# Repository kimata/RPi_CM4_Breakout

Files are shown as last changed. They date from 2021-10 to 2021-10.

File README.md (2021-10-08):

# RPi_CM4_Breakout

## 概要

Raspberry Pi Compute Module 4 から，通常の Raspberry Pi にあるピンヘッダを取り出す基板です．
サイズと穴位置は秋月のユニバーサル基板Ｃタイプに合わせてあります．

おまけで，I2C 用のピンヘッダ用のランドも設けています．

## 外観

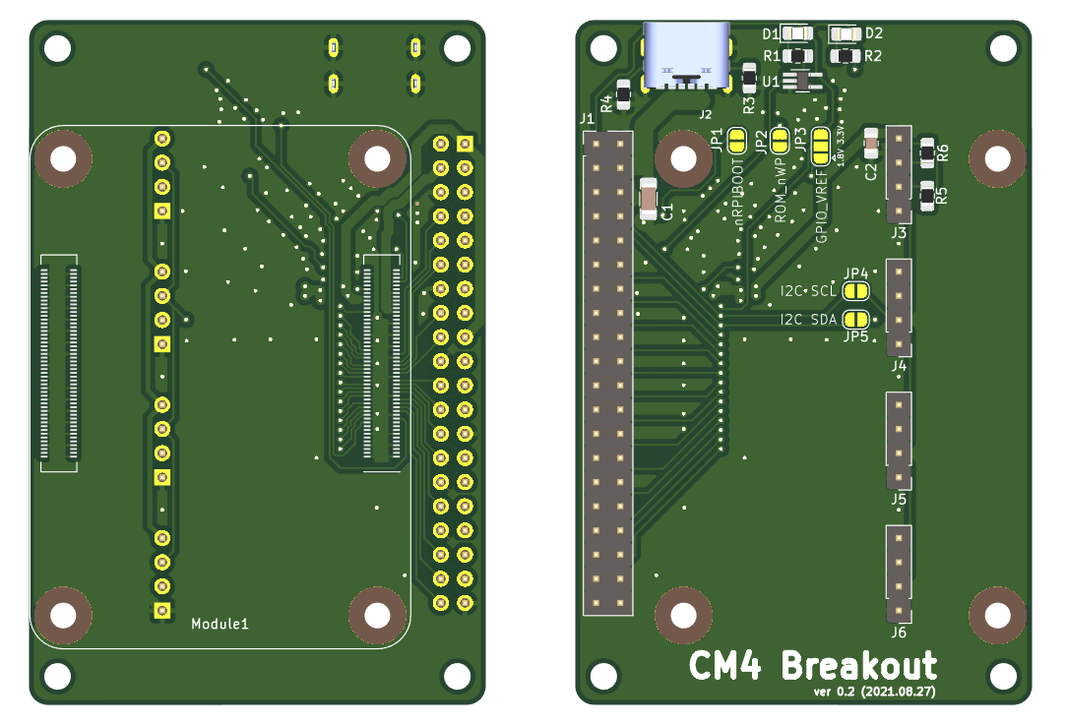
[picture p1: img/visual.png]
外観


## 回路図

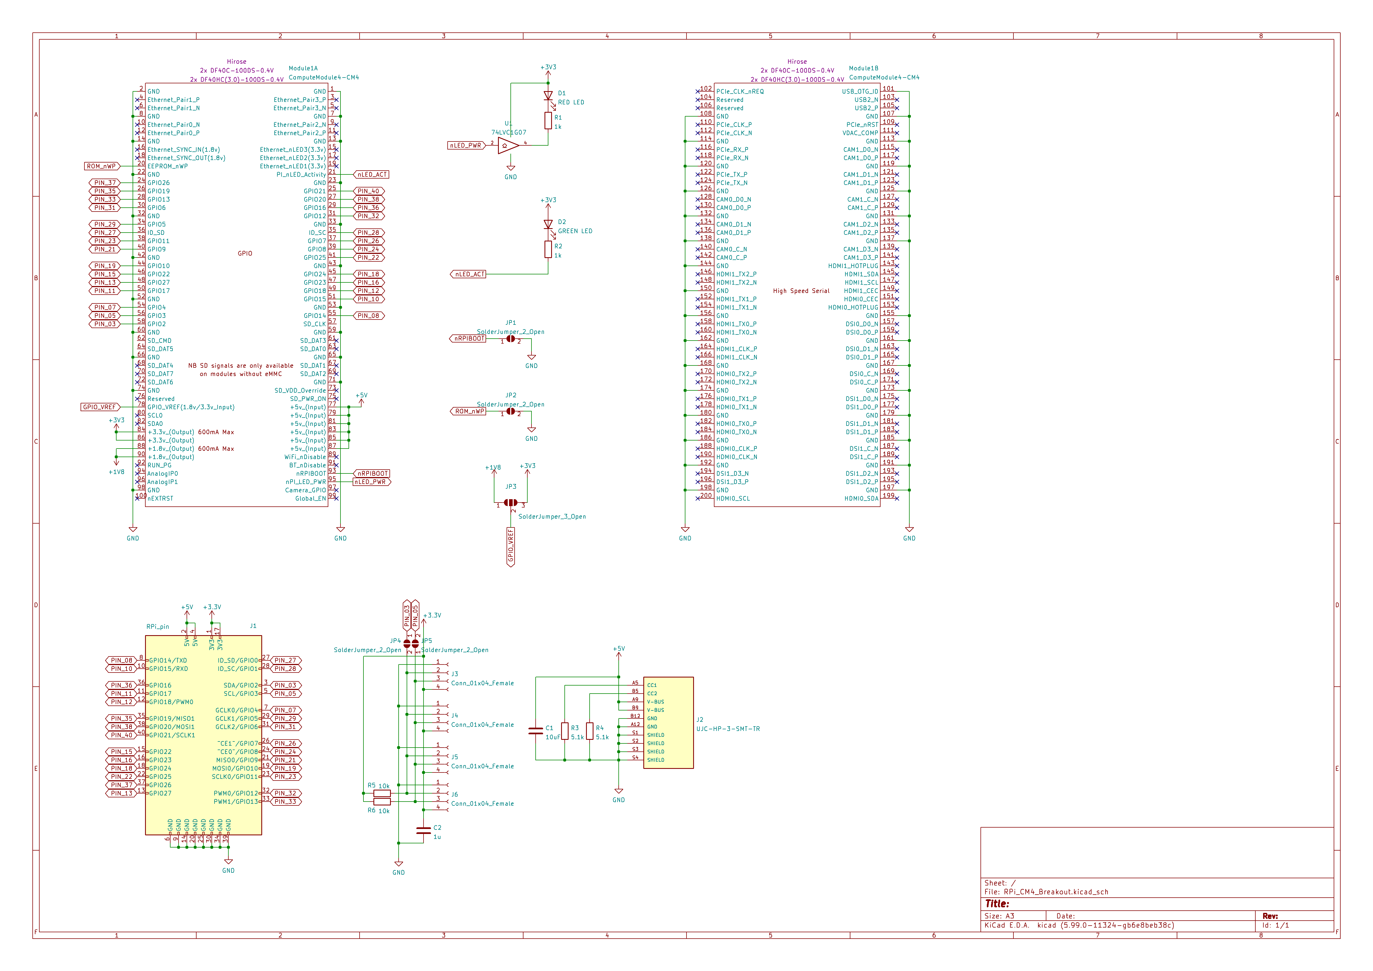
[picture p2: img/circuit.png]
回路図


## 基板の発注について

Raspberry Pi Compute Module 4 との接続に使う 100 ピンコネクタは手はんだが難しいので，この部分だけ基板メーカで実装してもらうのがおすすめです．

Elecrow にオーダーする際のシートを misc/Elecrow-PCBA-Quotation.xlsx においておきましたので参考にしてください．このファイルとガーバーデータを送れば製造できます．

料金は，私が製造したときは，送料込みで $168 でした．

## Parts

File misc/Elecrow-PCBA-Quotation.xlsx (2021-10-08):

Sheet: PCB Specification
Your PCB Specification
PCB Quantity | 10pcs
Layer | 2layer
PCB Thickness | 1.6mm
Dimensions | 48mm*72mm
Castellated Hole | No
PCB Color | Green
Surface Finish | HASL Lead Free
Copper Weight | 1oz
Text Color | White
Different Design | 1
Please find more PCB information on our on-line PCB ordering Page
https://www.elecrow.com/pcb-manufacturing.html

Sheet: BOM
Project Name
# | Reference | QTY | Value | Package | Manufacturer Part number | Description | SMD | THT | Original | Elecrow PN | Note
1 | J7, J8 | 1 |  |  | DF40HC(3.0)-100DS-0.4V(51 |  | 2 |  | Y
 |  |  |  |  |  | total： | 2 | 0
 | Declare：
 | 1、If the component should be original like Digi-key or Mouser，the component must have complete Manufacture part number

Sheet: Parts Mapping
Remarks:
- Apply solder paste only to J7 and J8 on the bottom surface and mount them.
- Flux should be cleaned after reflow.

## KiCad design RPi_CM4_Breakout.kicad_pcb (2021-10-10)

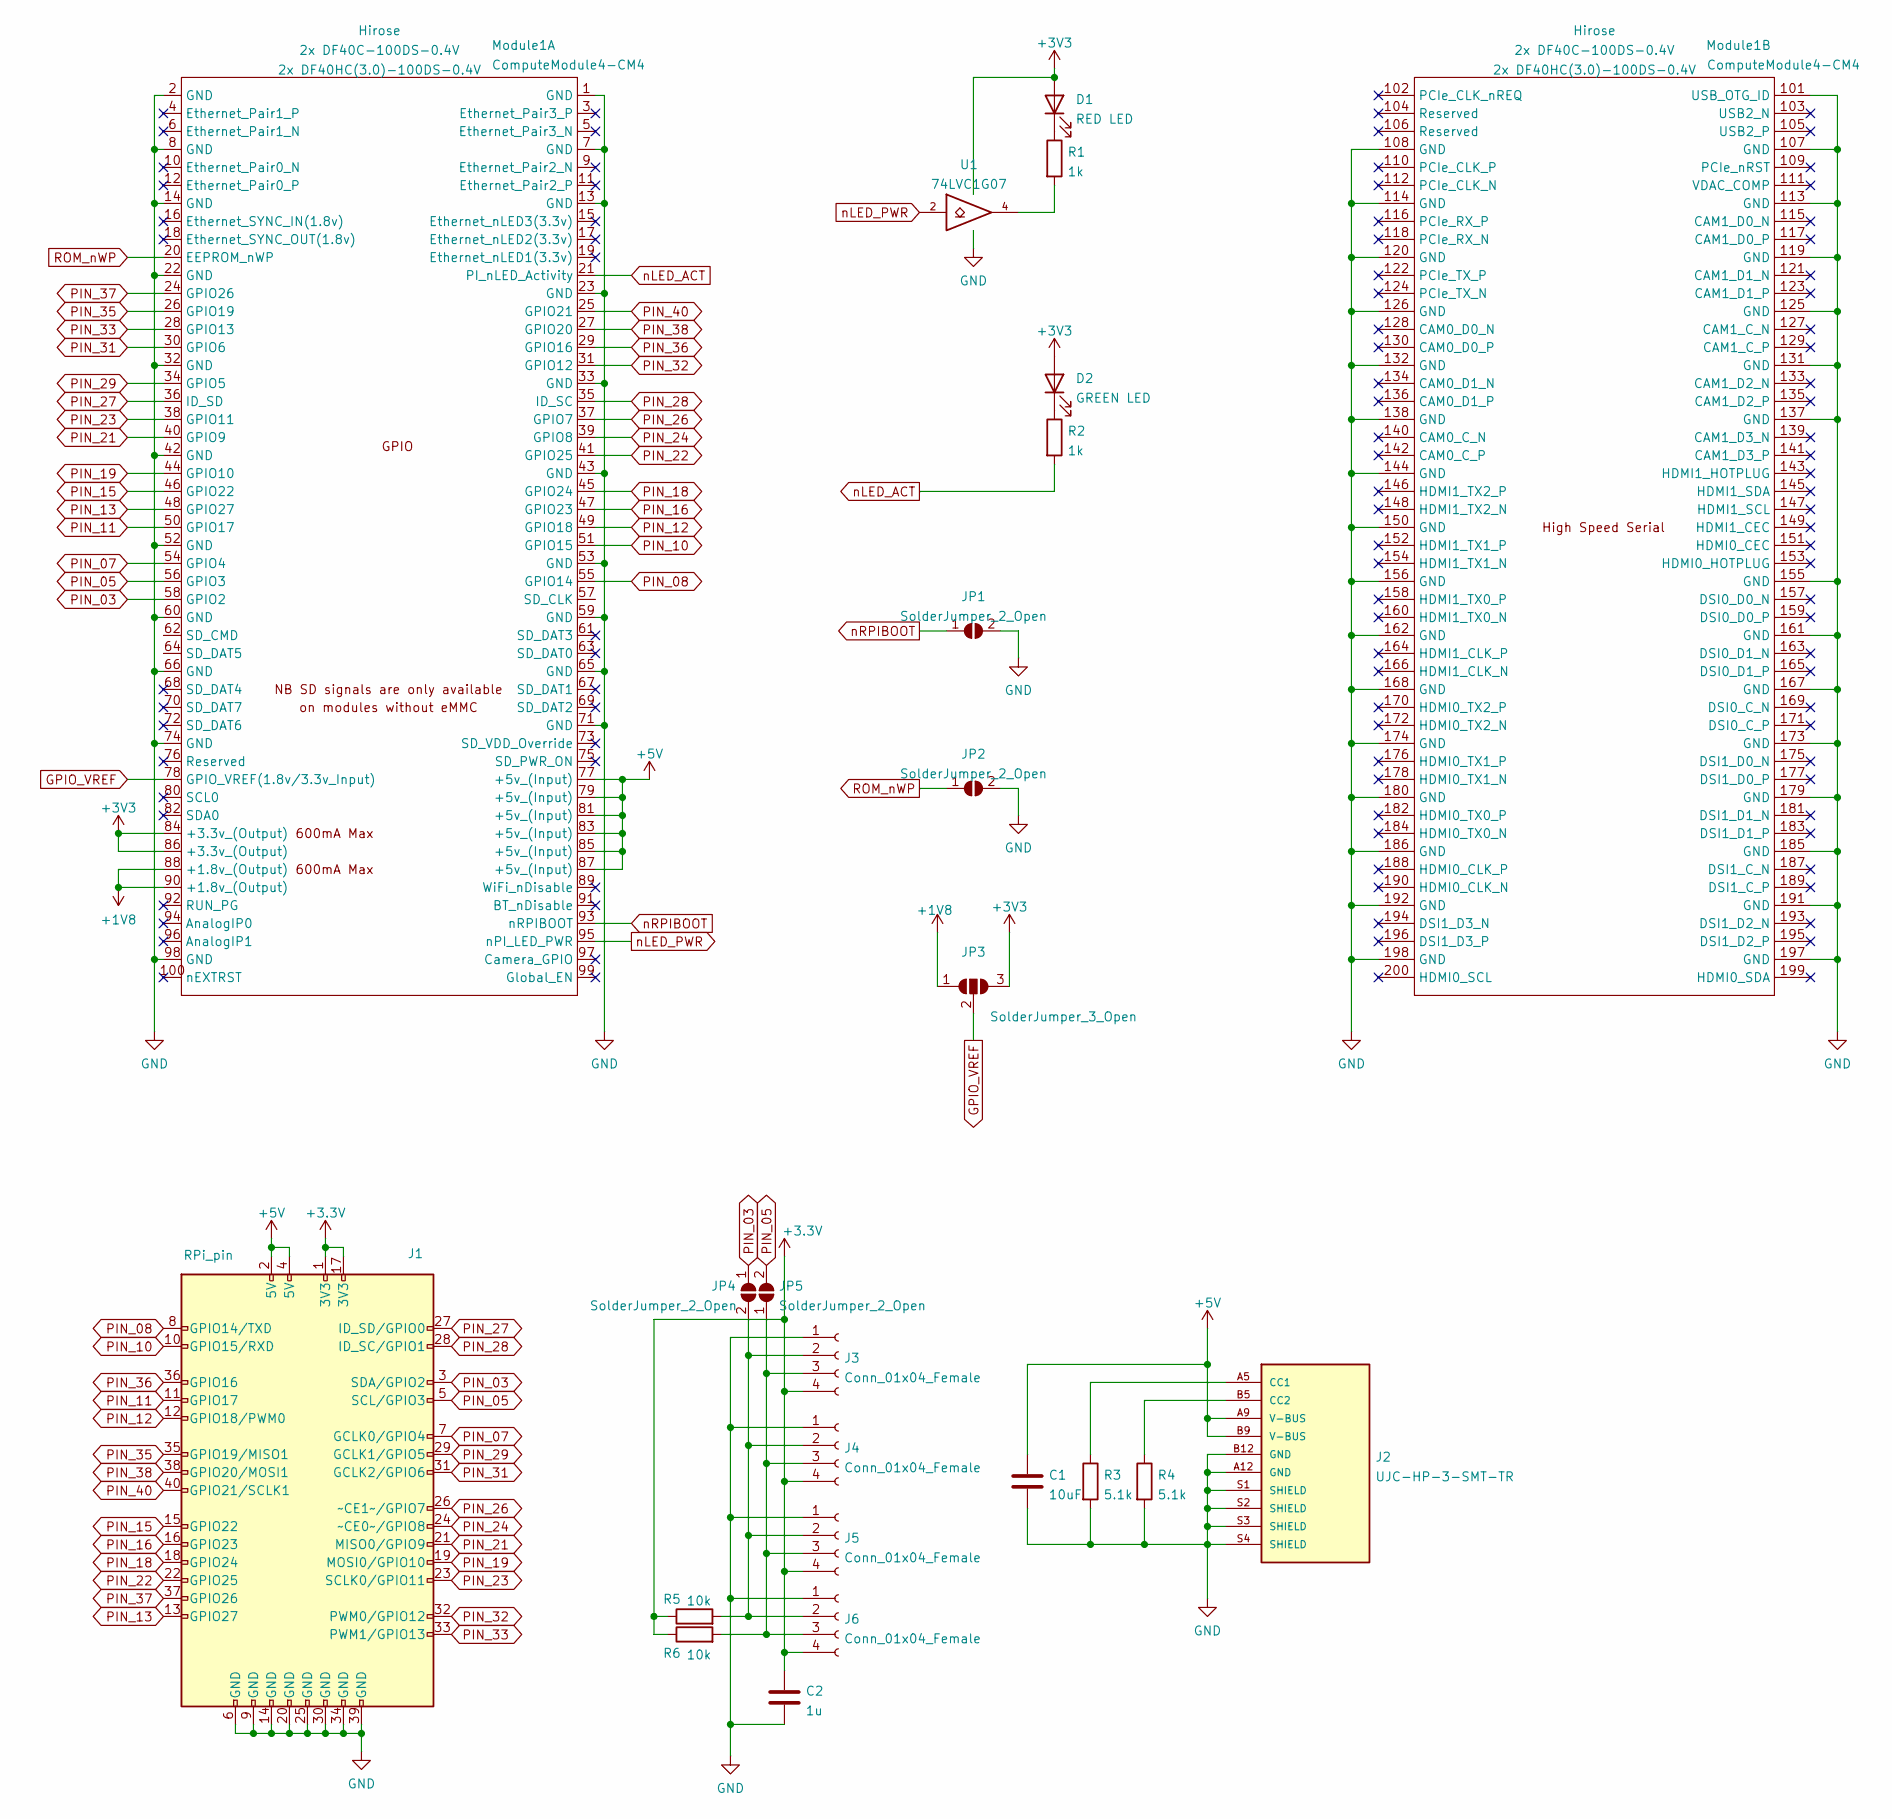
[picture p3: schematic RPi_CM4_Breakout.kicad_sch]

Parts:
C1: 10uF; C_1206_3216Metric_Pad1.33x1.80mm_HandSolder
C2: 1u; C_0805_2012Metric_Pad1.18x1.45mm_HandSolder
D1: RED LED; LED_0805_2012Metric_Pad1.15x1.40mm_HandSolder
D2: GREEN LED; LED_0805_2012Metric_Pad1.15x1.40mm_HandSolder
J1: RPi_pin; PinHeader_2x20_P2.54mm_Vertical
J2: UJC-HP-3-SMT-TR; CUI_UJC-HP-3-SMT-TR
J3, J4, J5, J6: Conn_01x04_Female; PinHeader_1x04_P2.54mm_Vertical
JP1, JP2, JP4, JP5: SolderJumper_2_Open; SolderJumper-2_P1.3mm_Open_RoundedPad1.0x1.5mm
JP3: SolderJumper_3_Open; SolderJumper-3_P1.3mm_Open_RoundedPad1.0x1.5mm
Module1: ComputeModule4-CM4; Raspberry-Pi-4-Compute-Module; MPN 2x DF40C-100DS-0.4V; Digi-Key_PN 2x H11615CT-ND
R1, R2: 1k; R_0805_2012Metric_Pad1.20x1.40mm_HandSolder
R3, R4: 5.1k; R_0805_2012Metric_Pad1.20x1.40mm_HandSolder
R5, R6: 10k; R_0805_2012Metric_Pad1.20x1.40mm_HandSolder
U1: 74LVC1G07; SOT-753

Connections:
+1V8: JP3.1 (A), Module1.88 (+1.8v_(Output)), Module1.90 (+1.8v_(Output))
+5V: C1.1, J1.2 (5V), J1.4 (5V), J2.A9 (V-BUS), J2.B9 (V-BUS), Module1.77 (+5v_(Input)), Module1.79 (+5v_(Input)), Module1.81 (+5v_(Input)), Module1.83 (+5v_(Input)), Module1.85 (+5v_(Input)), Module1.87 (+5v_(Input))
GND: C1.2, C2.2, J1.6 (GND), J1.9 (GND), J1.14 (GND), J1.20 (GND), J1.25 (GND), J1.30 (GND), J1.34 (GND), J1.39 (GND), J2.A12 (GND), J2.B12 (GND), J2.S1 (SHIELD), J2.S2 (SHIELD), J2.S3 (SHIELD), J2.S4 (SHIELD), J3.1, J4.1, J5.1, J6.1, JP1.2 (B), JP2.2 (B), Module1.1 (GND), Module1.2 (GND), Module1.7 (GND), Module1.8 (GND), Module1.13 (GND), Module1.14 (GND), Module1.22 (GND), Module1.23 (GND), Module1.32 (GND), Module1.33 (GND), Module1.42 (GND), Module1.43 (GND), Module1.52 (GND), Module1.53 (GND), Module1.59 (GND), Module1.60 (GND), Module1.65 (GND), Module1.66 (GND), Module1.71 (GND), Module1.74 (GND), Module1.98 (GND), Module1.101 (USB_OTG_ID), Module1.107 (GND), Module1.108 (GND), Module1.113 (GND), Module1.114 (GND), Module1.119 (GND), Module1.120 (GND), Module1.125 (GND), Module1.126 (GND), Module1.131 (GND), Module1.132 (GND), Module1.137 (GND), Module1.138 (GND), Module1.144 (GND), Module1.150 (GND), Module1.155 (GND), Module1.156 (GND), Module1.161 (GND), Module1.162 (GND), Module1.167 (GND), Module1.168 (GND), Module1.173 (GND), Module1.174 (GND), Module1.179 (GND), Module1.180 (GND), Module1.185 (GND), Module1.186 (GND), Module1.191 (GND), Module1.192 (GND), Module1.197 (GND), Module1.198 (GND), R3.2, R4.2, U1.3 (GND)
GPIO_VREF: JP3.2 (C), Module1.78 (GPIO_VREF(1.8v/3.3v_Input))
unnamed: D1.1 (K), R1.1
unnamed: D2.1 (K), R2.1
unnamed: J2.A5 (CC1), R3.1
unnamed: J2.B5 (CC2), R4.1
unnamed: J3.2, J4.2, J5.2, J6.2, JP4.2 (B), R5.2
unnamed: J3.3, J4.3, J5.3, J6.3, JP5.1 (A), R6.2
unnamed: R1.2, U1.4
PIN_03: J1.3 (SDA/GPIO2), JP4.1 (A), Module1.58 (GPIO2)
PIN_05: J1.5 (SCL/GPIO3), JP5.2 (B), Module1.56 (GPIO3)
PIN_07: J1.7 (GCLK0/GPIO4), Module1.54 (GPIO4)
PIN_08: J1.8 (GPIO14/TXD), Module1.55 (GPIO14)
PIN_10: J1.10 (GPIO15/RXD), Module1.51 (GPIO15)
PIN_11: J1.11 (GPIO17), Module1.50 (GPIO17)
PIN_12: J1.12 (GPIO18/PWM0), Module1.49 (GPIO18)
PIN_13: J1.13 (GPIO27), Module1.48 (GPIO27)
PIN_15: J1.15 (GPIO22), Module1.46 (GPIO22)
PIN_16: J1.16 (GPIO23), Module1.47 (GPIO23)
PIN_18: J1.18 (GPIO24), Module1.45 (GPIO24)
PIN_19: J1.19 (MOSI0/GPIO10), Module1.44 (GPIO10)
PIN_21: J1.21 (MISO0/GPIO9), Module1.40 (GPIO9)
PIN_22: J1.22 (GPIO25), Module1.41 (GPIO25)
PIN_23: J1.23 (SCLK0/GPIO11), Module1.38 (GPIO11)
PIN_24: J1.24 (~CE0~/GPIO8), Module1.39 (GPIO8)
PIN_26: J1.26 (~CE1~/GPIO7), Module1.37 (GPIO7)
PIN_27: J1.27 (ID_SD/GPIO0), Module1.36 (ID_SD)
PIN_28: J1.28 (ID_SC/GPIO1), Module1.35 (ID_SC)
PIN_29: J1.29 (GCLK1/GPIO5), Module1.34 (GPIO5)
PIN_31: J1.31 (GCLK2/GPIO6), Module1.30 (GPIO6)
PIN_32: J1.32 (PWM0/GPIO12), Module1.31 (GPIO12)
PIN_33: J1.33 (PWM1/GPIO13), Module1.28 (GPIO13)
PIN_35: J1.35 (GPIO19/MISO1), Module1.26 (GPIO19)
PIN_36: J1.36 (GPIO16), Module1.29 (GPIO16)
PIN_37: J1.37 (GPIO26), Module1.24 (GPIO26)
PIN_38: J1.38 (GPIO20/MOSI1), Module1.27 (GPIO20)
PIN_40: J1.40 (GPIO21/SCLK1), Module1.25 (GPIO21)
ROM_nWP: JP2.1 (A), Module1.20 (EEPROM_nWP)
nLED_ACT: Module1.21 (PI_nLED_Activity), R2.2
nLED_PWR: Module1.95 (nPI_LED_PWR), U1.2
nRPIBOOT: JP1.1 (A), Module1.93 (nRPIBOOT)

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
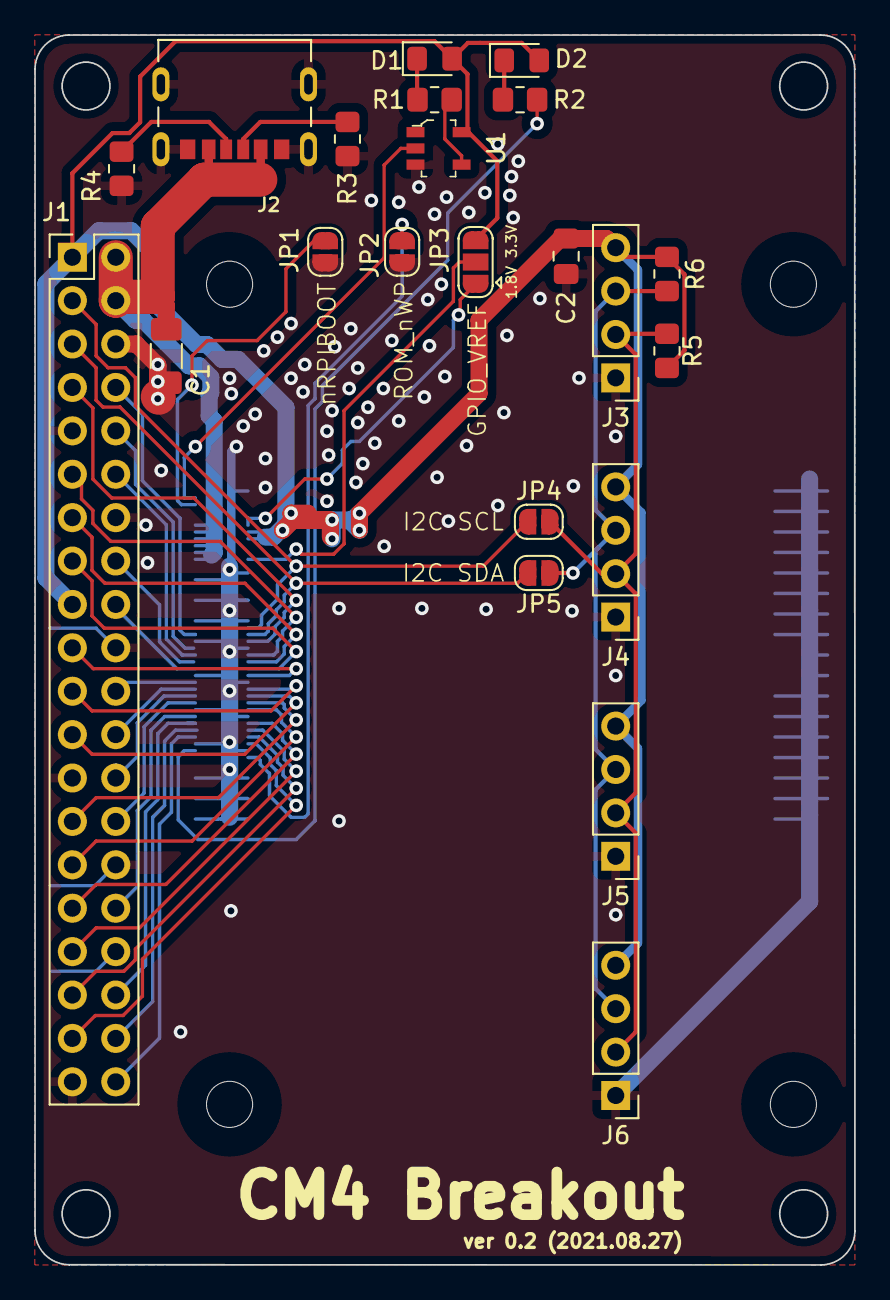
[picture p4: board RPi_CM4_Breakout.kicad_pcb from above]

Board: 2 copper layers, 48.0 x 72.0 mm, 23 parts (1 on the bottom side), 44 nets.

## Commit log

2021-08-17 feat: とりあえず完成
    [RPi_CM4_Sensor.kicad_pcb, RPi_CM4_Sensor.kicad_sch]
2021-08-17 fix: 名前を変更
    [RPi_CM4_Breakout.kicad_pcb, RPi_CM4_Breakout.kicad_sch]
2021-10-08 doc: ドキュメントを追加
    [Elecrow-PCBA-Quotation.xlsx]
2021-10-08 fix: 調整
    [RPi_CM4_Breakout.kicad_pcb]
2021-10-08 fix: ファイル名の誤記を修正
2021-10-08 doc: 基板サイズについて追記
2021-10-10 fix: LED ドライバのパッケージを SOT753 に変更
    [RPi_CM4_Breakout.kicad_pcb, RPi_CM4_Breakout.kicad_sch]
